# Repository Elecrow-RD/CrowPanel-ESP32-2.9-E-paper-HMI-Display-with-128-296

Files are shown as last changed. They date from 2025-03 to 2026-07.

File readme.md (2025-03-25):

### 1, Product picture

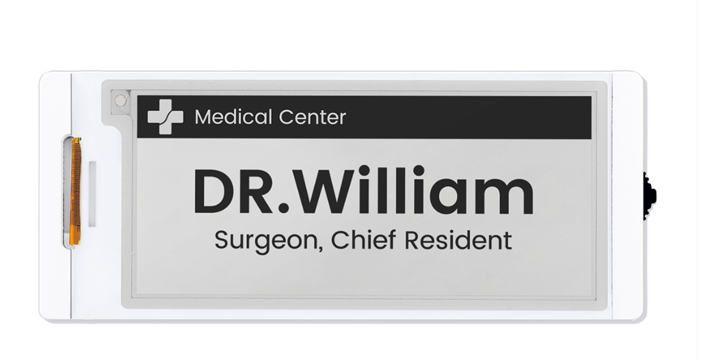
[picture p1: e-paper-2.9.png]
e-paper-2.9


### 2, Product version number

| | Hardware | Software | Remark |
| ---- | --- | --- | --- |
| 1 | V1.0 | V1.0 | latest |

### 3, product information

#### Display Module Specifications

- Size: 2.9 inch
- MCU: ESP32-S3-WROOM-1-N8R8, up to 240 MHz
- Flash: 8 MB
- PSRAM: 8 MB
- Material: Active Matrix Electrophoretic Display (AM EPD)
- Driver Chip: SSD1680Z
- Resolution: 128(H)*296(V) Pixel
- Pixel pitch: 0.227*0.226
- Viewing Angle: Full Viewing Angle
- Communication interface: 3-/4-wire SPI
- Interface: UART0 x1, BAT x1, GPIO x1, TF Card x1
- Button: Dial Switch x1, Menu Button x1, Back Button x1, REST Button x1, BOOT Button x1
- Development Environment: Arduino IDE、ESP IDF、MicroPython
- Display Color: Black and white
- Refresh Mode: Partial refresh (saves more power)
- Display Operation Voltage: 2.2~3.7V
- Acrylic Case: White Acrylic Case
- Operation Temperature: -0~50℃
- Storage Temperature: -25~70℃
- Active Area: 29.056(H)\*66.896(L) (H*L)

### 4, Use the driver module

| Name | dependency library |
| --- | --- |
| SSD1680Z | EPD<br />version=1.0.0 |

### 5,Quick Start

##### Arduino IDE starts

1.Download the library files used by this product to the 'libraries' folder.

C:\Users\Documents\Arduino\libraries\



2.Open the Arduino IDE

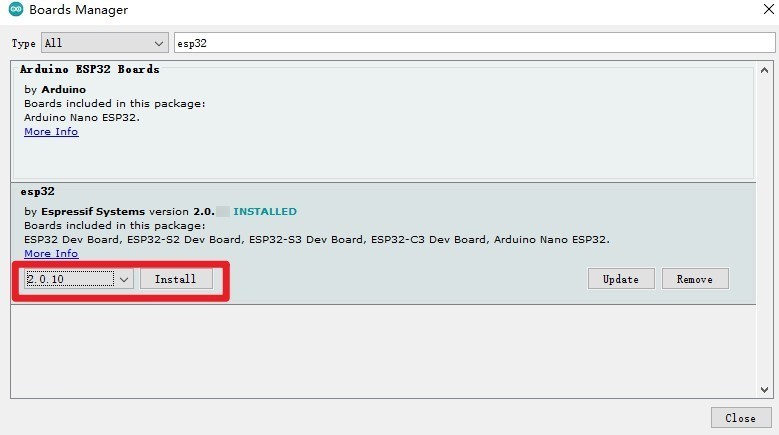
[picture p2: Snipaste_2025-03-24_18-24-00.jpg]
Snipaste_2025-03-24_18-24-00


3.Open the code configuration environment and burn it

setting

### 6,Folder structure.

|--3D file： Contains 3D model files (.stp) for the hardware. These files can be used for visualization, enclosure design, or integration into CAD software.

|--Datasheet: Includes datasheets for components used in the project, providing detailed specifications, electrical characteristics, and pin configurations.

|--Eagle_SCH&PCB: Contains **Eagle CAD** schematic (`.sch`) and PCB layout (`.brd`) files. These are used for circuit design and PCB manufacturing.

|--example: Provides example code and projects to demonstrate how to use the hardware and libraries. These examples help users get started quickly.

|--factory_firmware: Stores pre-compiled factory firmware that can be directly flashed onto the device. This ensures the device runs the default functionality.

|--factory_sourcecode: Contains the source code for the factory firmware, allowing users to modify and rebuild the firmware as needed.

### 7,Pin definition

#define SCK 12

#define MOSI 11

#define RES 47

#define DC 46

#define CS 45

#define BUSY 48

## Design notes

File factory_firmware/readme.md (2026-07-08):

# How to install the factory demo firmware with flash download tool?

#### 1.Preparation:

- USB C cable
- Laptop/PC
- Crowpanel Advance HMI ESP32 AI Display
- Flash download tool

Check whether the materials on the PCBA board are defective. Such as less material, false welding, tin and other bad phenomena.

#### 2.Flash the firmware 

##### Step1 Connect the ESP32 display to the laptop/PC with USB-C cable. The power indicator will light up.

##### Step2 Open the flash download tool. 

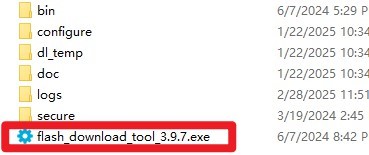
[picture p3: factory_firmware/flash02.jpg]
flash02


For the  Crowpanel Advance HMI ESP32 AI Display, the chip select ESP32-S3:

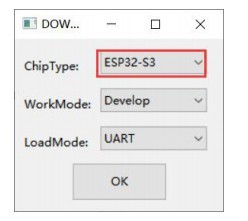
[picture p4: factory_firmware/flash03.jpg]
flash03


##### Step3

①Choose the firmware files;

flash0

②Enter the address: 

boot_app0.bin------0xe000

xxxx.ino.bin--------0x10000

xxxx.ino.bootloader.bin------0x0

xxxx.ino.partitions.bin-------0x8000

③Check the firmware files;

④Select the correct port number;

⑤Click “Start” to download

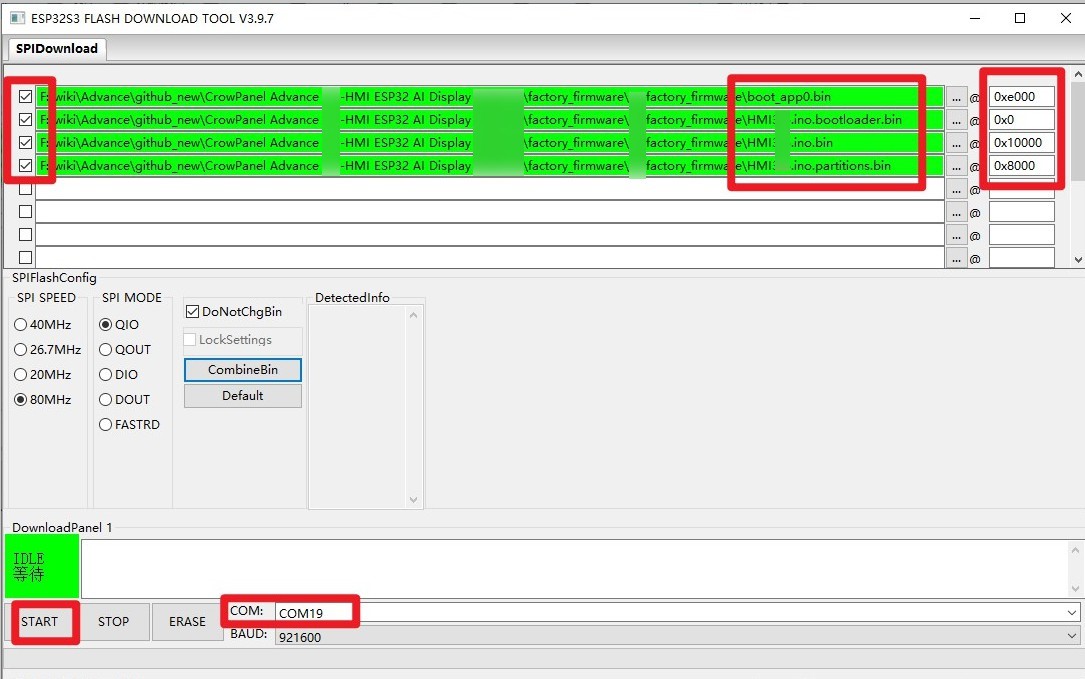
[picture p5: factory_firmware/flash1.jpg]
flash1


##### Step5 After the download is complete, blue FINISH will be displayed, and the progress bar at the bottom shows that it has come to an end.

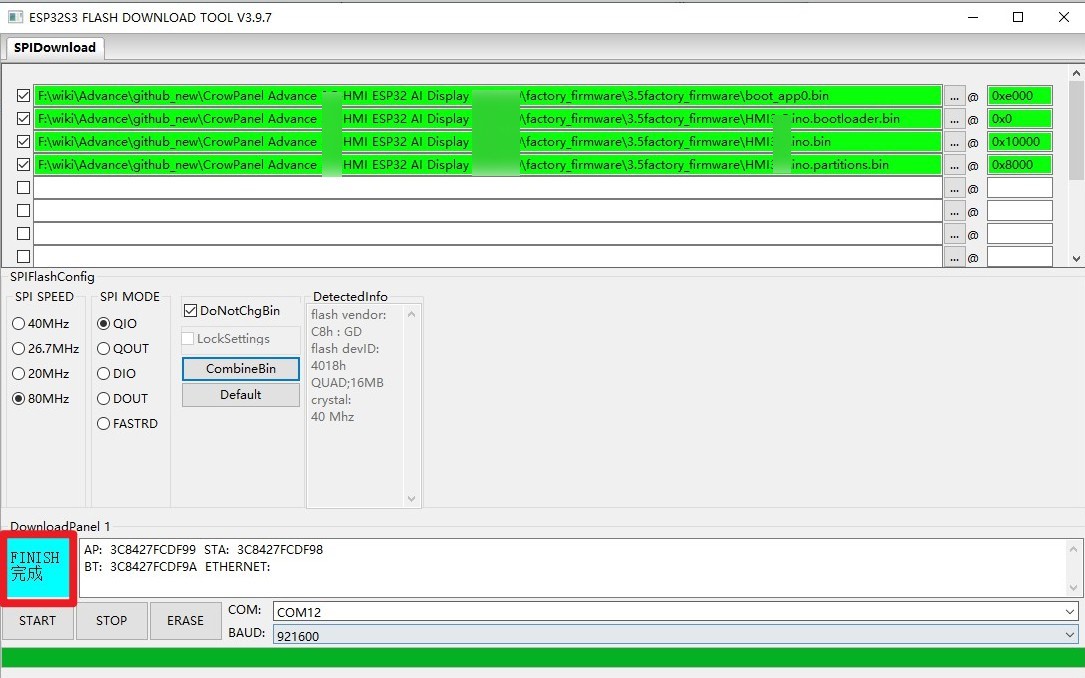
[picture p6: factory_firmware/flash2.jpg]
flash2


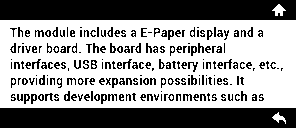
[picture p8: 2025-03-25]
factory_sourecode/2.9_tow/pic/NEW_UI_2-9_BW_/NEW_UI_2-9_BW_Product-Description-03.bmp

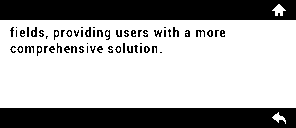
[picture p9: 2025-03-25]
factory_sourecode/2.9_tow/pic/NEW_UI_2-9_BW_/NEW_UI_2-9_BW_Product-Description-06.bmp

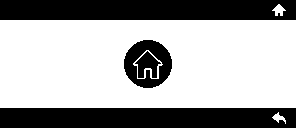
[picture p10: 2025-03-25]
factory_sourecode/2.9_tow/pic/ui_2-9_202406_02/UI_2_9_202406返回主界面.bmp

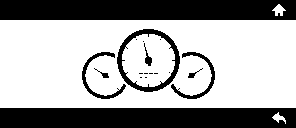
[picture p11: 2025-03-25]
factory_sourecode/2.9_tow/pic/NEW_UI_2-9_BW_/NEW_UI_2-9_BW_img-03.bmp

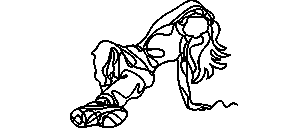
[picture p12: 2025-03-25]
factory_sourecode/2.9_tow/pic/NEW_UI_2-9_BW_/NEW_UI_2-9_BW_img-06.bmp

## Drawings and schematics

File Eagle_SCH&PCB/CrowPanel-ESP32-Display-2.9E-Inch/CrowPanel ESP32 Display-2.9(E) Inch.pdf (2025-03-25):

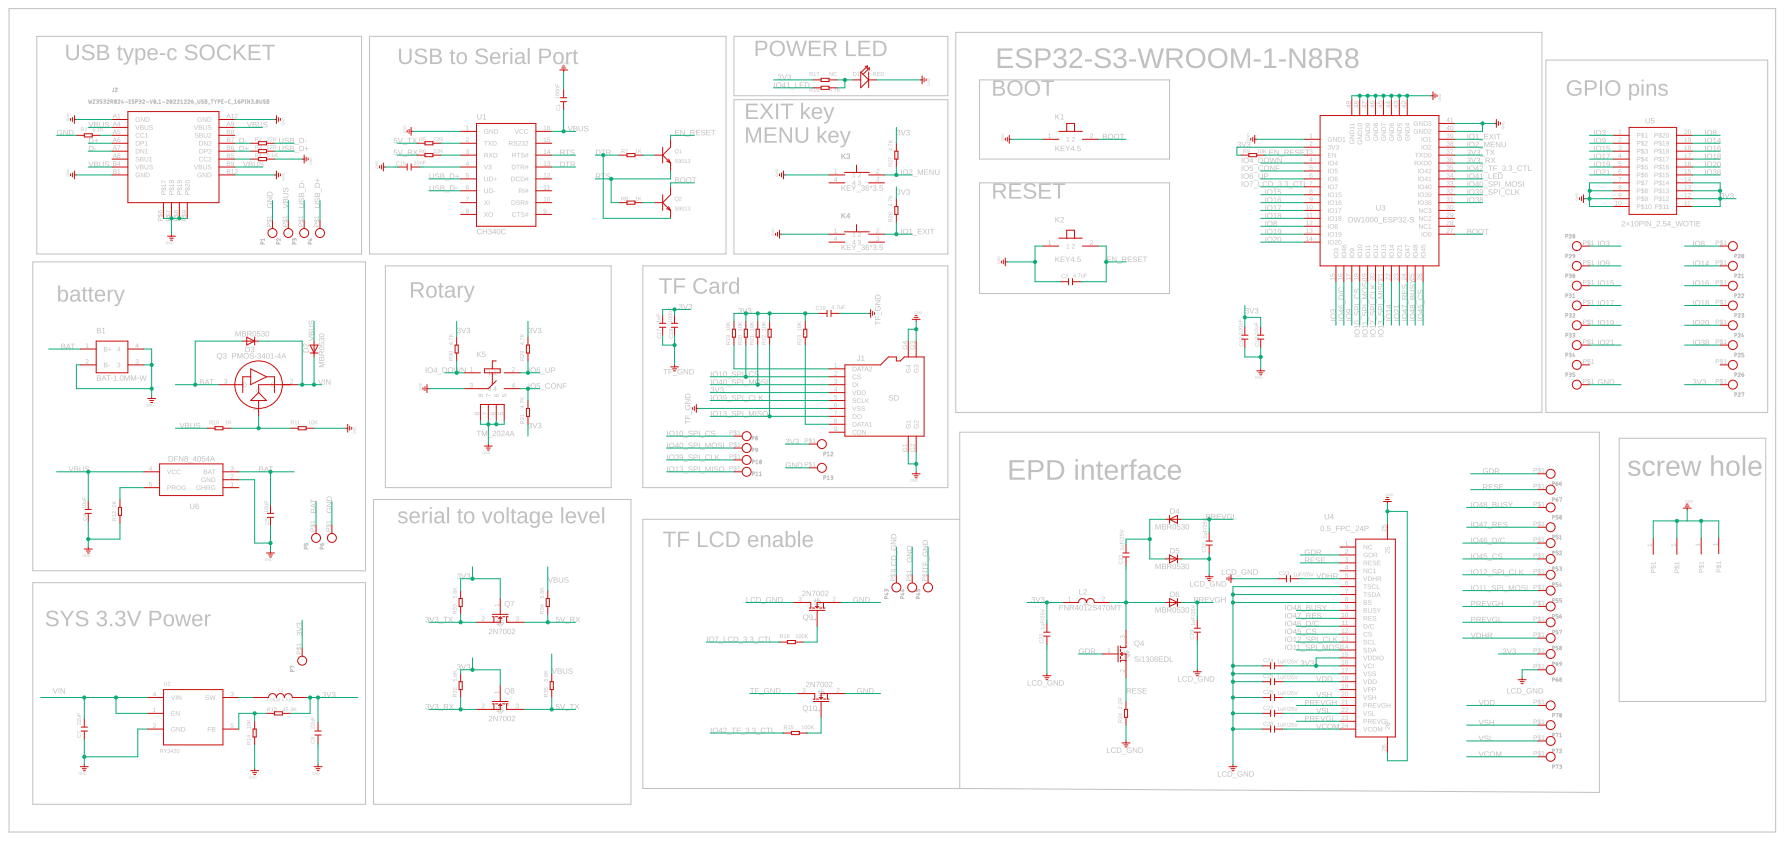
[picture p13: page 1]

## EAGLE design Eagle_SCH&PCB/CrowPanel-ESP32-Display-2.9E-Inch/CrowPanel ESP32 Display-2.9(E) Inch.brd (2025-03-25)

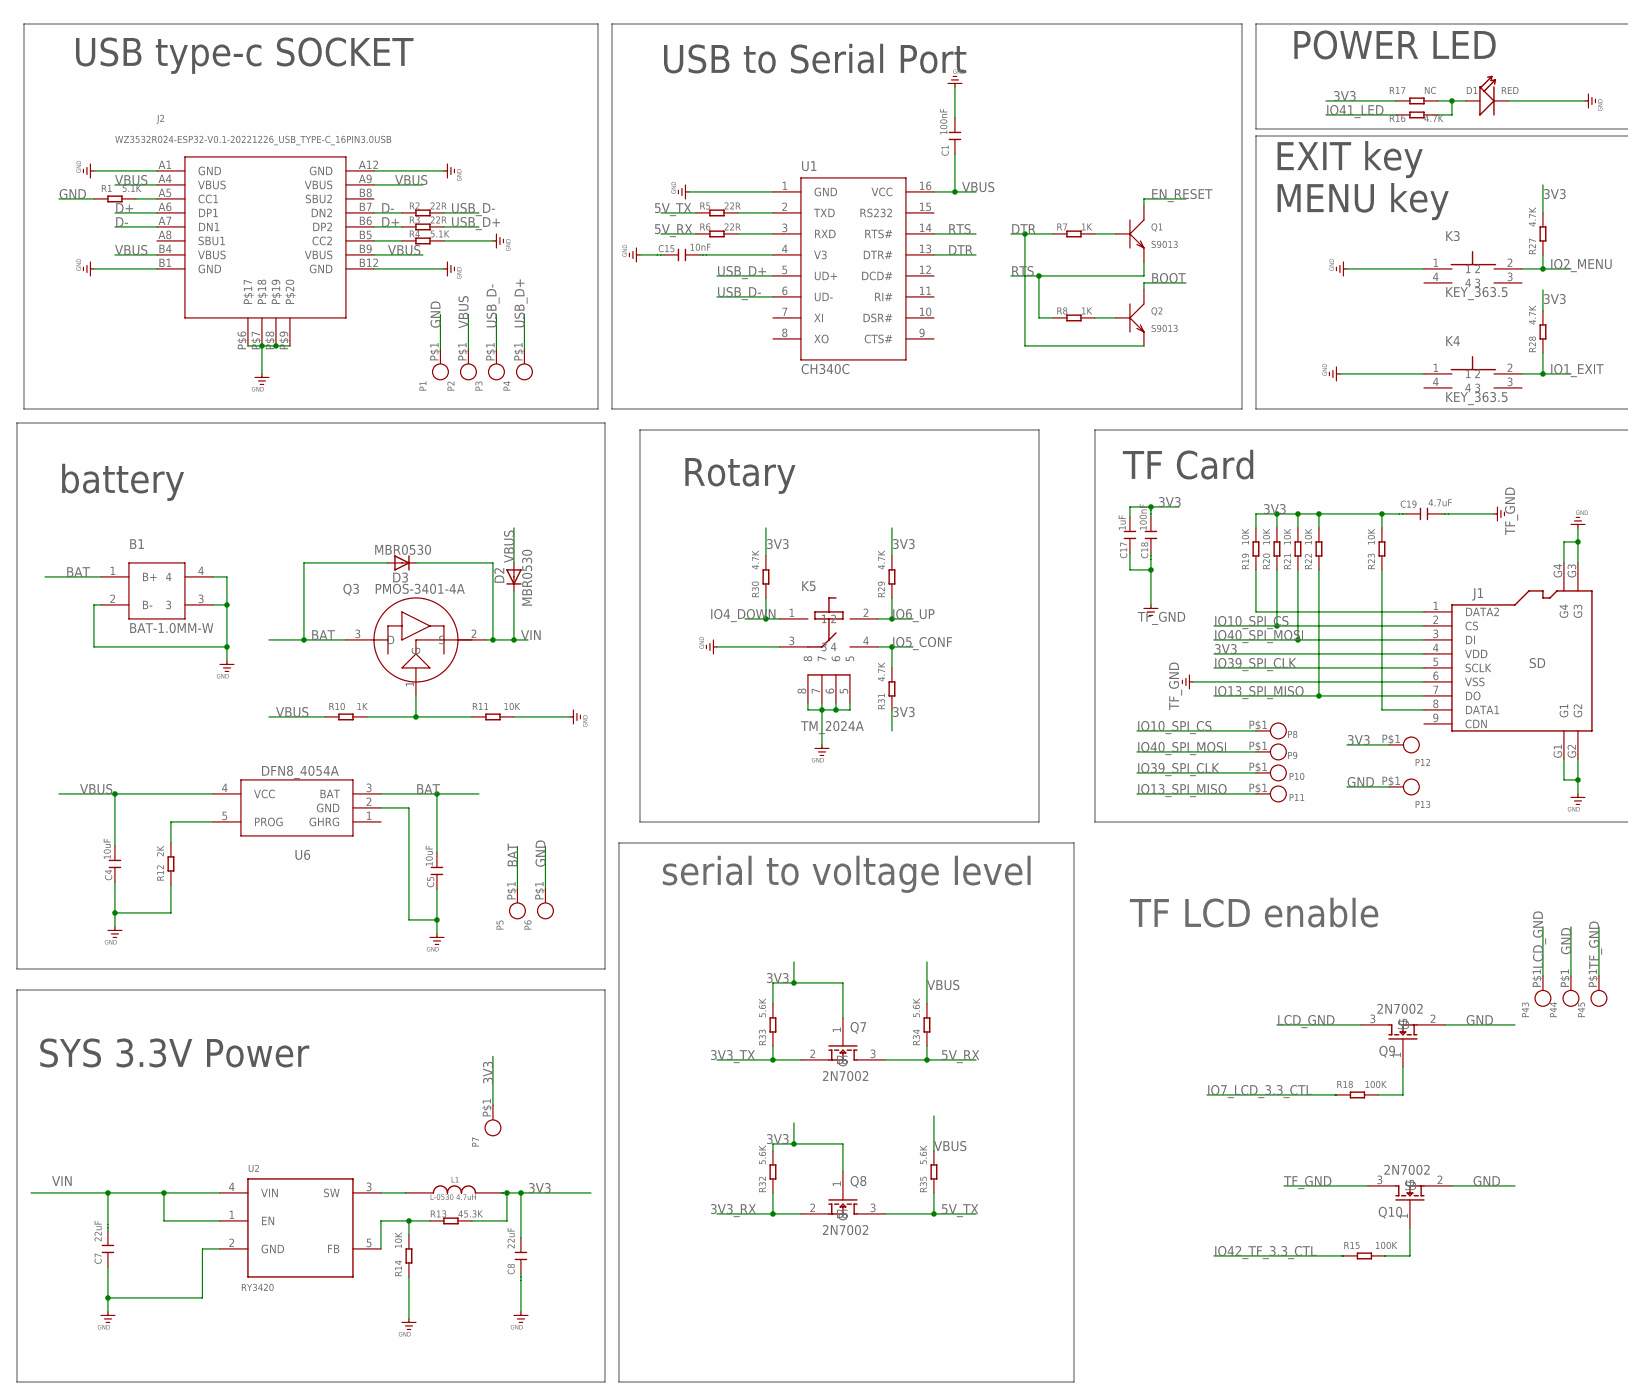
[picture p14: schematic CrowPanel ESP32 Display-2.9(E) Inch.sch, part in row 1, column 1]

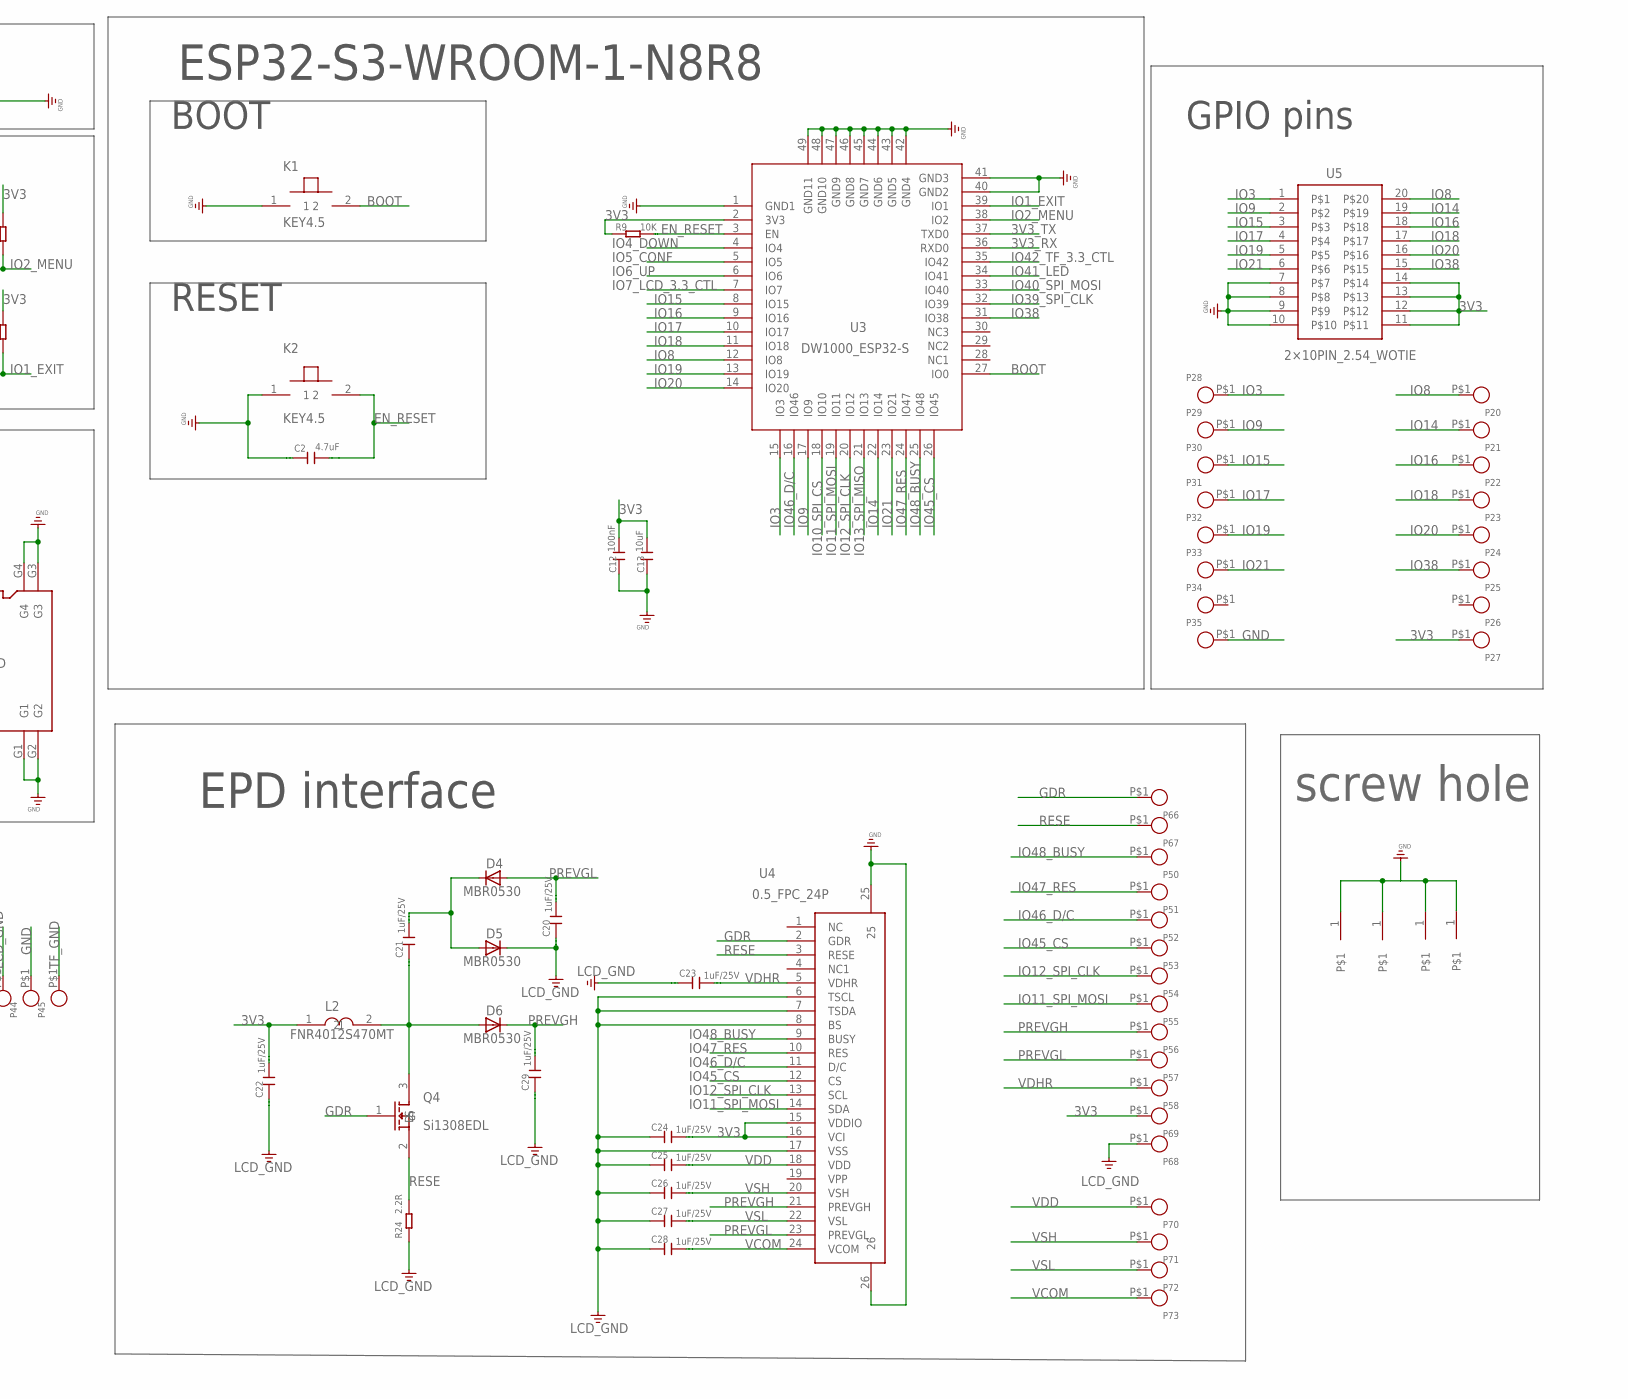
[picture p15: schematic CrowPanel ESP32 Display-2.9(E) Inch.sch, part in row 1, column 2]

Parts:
B1: BAT-1.0MM-W; SH1.0MM-W
C1, C12, C18: 100nF; 0402
C2, C19: 4.7uF; 0402
C4, C5, C13: 10uF; 0402
C7, C8: 22uF; 0603
C15: 10nF; 0402
C17: 1uF; 0402
C20, C21, C22, C23, C24, C25, C26, C27, C28, C29: 1uF/25V; 0402
D1: RED; A_XBJ_DISCRETE_LED-0603
D2, D3, D4, D5, D6: MBR0530; DIODE_SOD123
H1, H2, H3, H4: DW1000_3.2MM-5
J1: SD; CONNECTOR_9P-SMD-W/-RING
J2: WZ3532R024-ESP32-V0.1-20221226_USB_TYPE-C_16PIN3.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; WZ3532R024-ESP32-V0.1-20221226_KEVIN_3.0TYPEC-SMD
K1, K2: KEY4.5; KEY-4.5
K3, K4: KEY_363.5; KEY_3*6*3.5
K5: TM_2024A
L1: L-0530 4.7uH; L0530
L2: FNR4012S470MT
P1, P2, P3, P4, P5, P6, P7, P8, P9, P10, P11, P12, P13, P20, P21, P22, P23, P24, P25, P26, P27, P28, P29, P30, P31, P32, P33, P34, P35, P43, P44, P45, P50, P51, P52, P53, P54, P55, P56, P57, P58, P66, P67, P68, P69, P70, P71, P72, P73: CROWPI_POW_PADPAD-1.0MM; CROWPI_POW_PAD-1.0MM
Q1, Q2: S9013; DISCRETE_SOT23$1
Q3: PMOS-3401-4A; DFN8_SOT-23
Q4: Si1308EDL; SOT-323_W
Q7, Q8, Q9, Q10: 2N7002; SOT23-3_W
R1, R4: 5.1K; 0402
R2, R3, R5, R6: 22R; 0402
R7, R8, R10: 1K; 0402
R9, R11, R14, R19, R20, R21, R22, R23: 10K; 0402
R12: 2K; 0402
R13: 45.3K; 0402
R15, R18: 100K; 0402
R16, R27, R28, R29, R30, R31: 4.7K; A9G_DISCRETE_R0603
R17: NC; A9G_DISCRETE_R0603
R24: 2.2R; 0402
R32, R33, R34, R35: 5.6K; 0402
U1: CH340C; A_XBJ_SOP-16
U2: RY3420; CROWBOT_-V1.0-20220525_A_XBJ_SOT23-5
U3: DW1000_ESP32-S; DW1000_ESP32-S3
U4: 0.5_FPC_24P
U5: 2×10PIN_2.54_WOTIE; 2*10PIN_2.54_WOTIE
U6: DFN8_4054A; DFN8_SOP23-5

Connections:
3V3: C8.2, C12.2, C13.2, C17.2, C18.2, C19.1, C22.1, C24.1, J1.4 (VDD), L1.P$2 (2), L2.1, P7.P$1, P12.P$1, P27.P$1, P69.P$1, Q7.1 (G), Q8.1 (G), R9.1, R13.2, R17.1, R19.2, R20.2, R21.2, R22.2, R23.2, R27.2, R28.2, R29.2, R30.2, R31.1, R32.2, R33.2, U3.2 (3V3), U4.15 (VDDIO), U4.16 (VCI), U5.11, U5.12, U5.13, U5.14
3V3_RX: Q8.2 (S), R32.1, U3.36 (RXD0)
3V3_TX: Q7.2 (S), R33.1, U3.37 (TXD0)
5V_RX: Q7.3 (D), R6.1, R34.1
5V_TX: Q8.3 (D), R5.1, R35.1
BAT: B1.1 (B+), C5.2, D3.A, P5.P$1, Q3.3 (D), U6.3 (BAT)
BOOT: K1.2, Q2.3 (C), U3.27 (IO0)
D+: J2.A6 (DP1), J2.B6 (DP2), R3.1
D-: J2.A7 (DN1), J2.B7 (DN2), R2.1
DTR: Q2.2 (E), R7.1, U1.13 (DTR#)
EN_RESET: C2.2, K2.2, Q1.3 (C), R9.2, U3.3 (EN)
GDR: P66.P$1, Q4.1 (G), U4.2 (GDR)
GND: B1.2 (B-), B1.3, B1.4, C1.2, C2.1, C4.1, C5.1, C7.1, C8.1, C12.1, C13.1, C15.1, D1.-, H1.1, H2.1, H3.1, H4.1, J1.G1, J1.G2, J1.G3, J1.G4, J2.A1 (GND), J2.A12 (GND), J2.B1 (GND), J2.B12 (GND), J2.P$6, J2.P$7, J2.P$8, J2.P$9, K1.1, K2.1, K3.1, K4.1, K5.3, K5.5, K5.6, K5.7, K5.8, P1.P$1, P6.P$1, P13.P$1, P35.P$1, P44.P$1, Q9.2 (S), Q10.2 (S), R1.1, R4.2, R11.2, R12.1, R14.1, U1.1 (GND), U2.2 (GND), U3.1 (GND1), U3.40 (GND2), U3.41 (GND3), U3.42 (GND4), U3.43 (GND5), U3.44 (GND6), U3.45 (GND7), U3.46 (GND8), U3.47 (GND9), U3.48 (GND10), U3.49 (GND11), U4.25, U4.26, U5.7, U5.8, U5.9, U5.10, U6.2 (GND)
IO1_EXIT: K4.2, R28.1, U3.39 (IO1)
IO2_MENU: K3.2, R27.1, U3.38 (IO2)
IO3: P28.P$1, U3.15 (IO3), U5.1
IO4_DOWN: K5.1, R30.1, U3.4 (IO4)
IO5_CONF: K5.4, R31.2, U3.5 (IO5)
IO6_UP: K5.2, R29.1, U3.6 (IO6)
IO7_LCD_3.3_CTL: R18.1, U3.7 (IO7)
IO8: P20.P$1, U3.12 (IO8), U5.20
IO9: P29.P$1, U3.17 (IO9), U5.2
IO10_SPI_CS: J1.2 (CS), P8.P$1, R20.1, U3.18 (IO10)
IO11_SPI_MOSI: P55.P$1, U3.19 (IO11), U4.14 (SDA)
IO12_SPI_CLK: P54.P$1, U3.20 (IO12), U4.13 (SCL)
IO13_SPI_MISO: J1.7 (DO), P11.P$1, R22.1, U3.21 (IO13)
IO14: P21.P$1, U3.22 (IO14), U5.19
IO15: P30.P$1, U3.8 (IO15), U5.3
IO16: P22.P$1, U3.9 (IO16), U5.18
IO17: P31.P$1, U3.10 (IO17), U5.4
IO18: P23.P$1, U3.11 (IO18), U5.17
IO19: P32.P$1, U3.13 (IO19), U5.5
IO20: P24.P$1, U3.14 (IO20), U5.16
IO21: P33.P$1, U3.23 (IO21), U5.6
IO38: P25.P$1, U3.31 (IO38), U5.15
IO39_SPI_CLK: J1.5 (SCLK), P10.P$1, U3.32 (IO39)
IO40_SPI_MOSI: J1.3 (DI), P9.P$1, R21.1, U3.33 (IO40)
IO41_LED: R16.1, U3.34 (IO41)
IO42_TF_3.3_CTL: R15.1, U3.35 (IO42)
IO45_CS: P53.P$1, U3.26 (IO45), U4.12 (CS)
IO46_D/C: P52.P$1, U3.16 (IO46), U4.11 (D/C)
IO47_RES: P51.P$1, U3.24 (IO47), U4.10 (RES)
IO48_BUSY: P50.P$1, U3.25 (IO48), U4.9 (BUSY)
LCD_GND: C20.2, C22.2, C23.2, C24.2, C25.2, C26.2, C27.2, C28.2, C29.2, D5.C, P43.P$1, P68.P$1, Q9.3 (D), R24.1, U4.6 (TSCL), U4.7 (TSDA), U4.8 (BS), U4.17 (VSS)
unnamed: Q1.1 (B), R7.2
unnamed: R5.2, U1.2 (TXD)
unnamed: R6.2, U1.3 (RXD)
unnamed: Q2.1 (B), R8.2
unnamed: J2.A5 (CC1), R1.2
unnamed: Q3.1 (G), R10.2, R11.1
unnamed: Q9.1 (G), R18.2
unnamed: Q10.1 (G), R15.2
unnamed: R13.1, R14.2, U2.5 (FB)
unnamed: J1.1 (DATA2), R19.1
unnamed: L1.P$1 (1), U2.3 (SW)
unnamed: J2.B5 (CC2), R4.1
unnamed: C15.2, U1.4 (V3)
unnamed: R12.2, U6.5 (PROG)
unnamed: J1.8 (DATA1), R23.1
unnamed: D1.+, R16.2, R17.2
unnamed: C21.1, D4.C, D5.A
unnamed: C21.2, D6.A, L2.2, Q4.3 (D)
PREVGH: C29.1, D6.C, P56.P$1, U4.21 (PREVGH)
PREVGL: C20.1, D4.A, P57.P$1, U4.23 (PREVGL)
RESE: P67.P$1, Q4.2 (S), R24.2, U4.3 (RESE)
RTS: Q1.2 (E), R8.1, U1.14 (RTS#)
TF_GND: C17.1, C18.1, C19.2, J1.6 (VSS), P45.P$1, Q10.3 (D)
USB_D+: P4.P$1, R3.2, U1.5 (UD+)
USB_D-: P3.P$1, R2.2, U1.6 (UD-)
VBUS: C1.1, C4.2, D2.A, J2.A4 (VBUS), J2.A9 (VBUS), J2.B4 (VBUS), J2.B9 (VBUS), P2.P$1, R10.1, R34.2, R35.2, U1.16 (VCC), U6.4 (VCC)
VCOM: C28.1, P73.P$1, U4.24 (VCOM)
VDD: C25.1, P70.P$1, U4.18 (VDD)
VDHR: C23.1, P58.P$1, U4.5 (VDHR)
VIN: C7.2, D2.C, D3.C, Q3.2 (S), U2.1 (EN), U2.4 (VIN)
VSH: C26.1, P71.P$1, U4.20 (VSH)
VSL: C27.1, P72.P$1, U4.22 (VSL)

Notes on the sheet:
USB type-c SOCKET
USB to Serial Port
POWER LED
EXIT key MENU key
ESP32-S3-WROOM-1-N8R8
GPIO pins
EPD interface
TF Card
Rotary
SYS 3.3V Power
battery
BOOT
RESET
serial to voltage level
TF LCD enable
screw hole

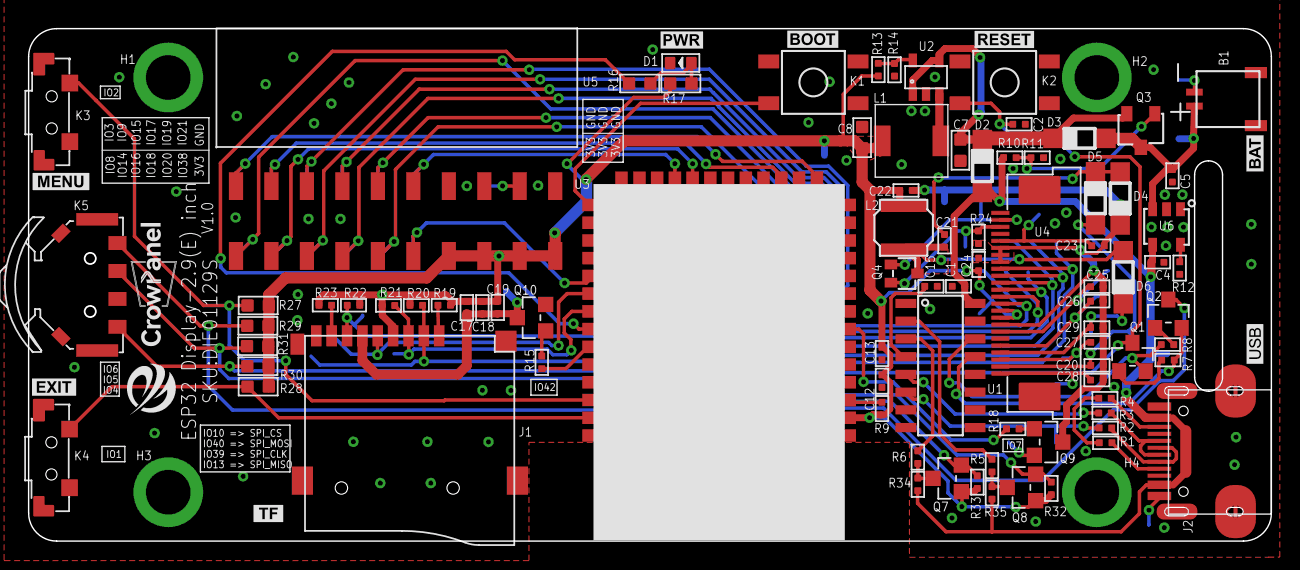
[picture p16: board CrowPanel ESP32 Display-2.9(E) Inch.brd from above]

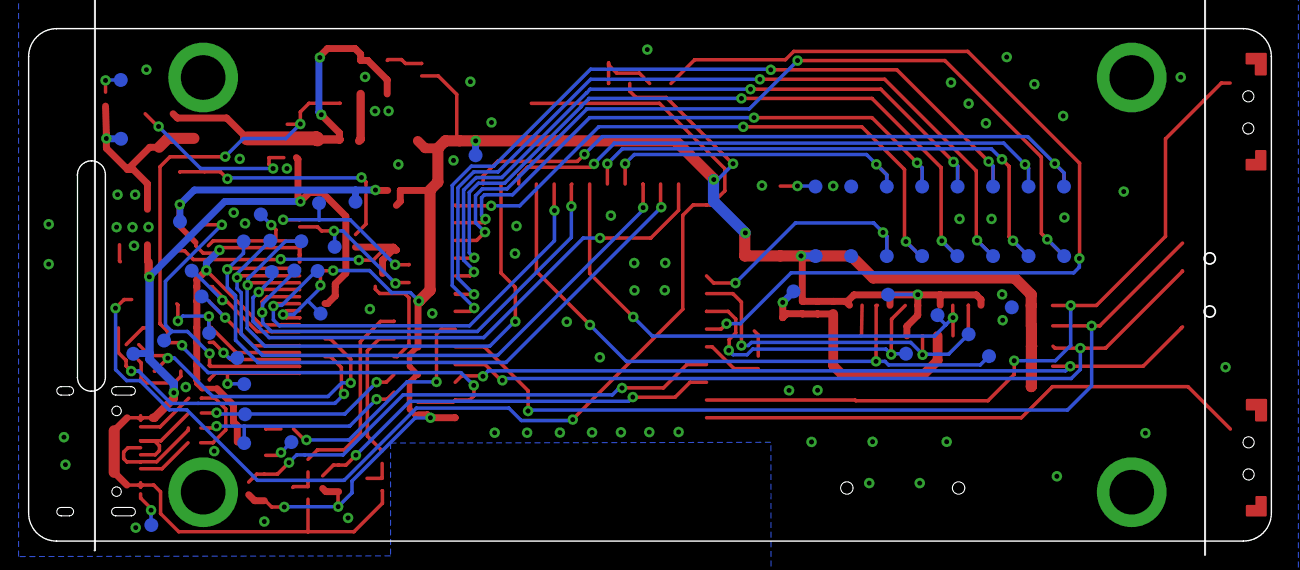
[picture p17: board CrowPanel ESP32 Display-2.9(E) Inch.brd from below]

Board: 2 copper layers, 89.0 x 36.7 mm, 140 parts (49 on the bottom side), 76 nets.

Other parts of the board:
U$30: LOGO-1
U$41: LOGO-MIN

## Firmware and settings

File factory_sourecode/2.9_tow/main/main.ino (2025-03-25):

#include <Arduino.h>
#include "EPD.h"
#include "pic.h"
#include "Pic_boot_screen.h"
#include "pic_menu.h"
#include "pic_home.h"
#include "pic_description.h"
#include "pic_image.h"
#include "pic_scenario.h"

#include "FS.h"
#include "SD.h"
#include <WiFi.h>
//#include <esp_wifi.h>

#define FILE_NAME "/book.txt"
#define SD_MOSI 40
#define SD_MISO 13
#define SD_SCK 39
#define SD_CS 10
SPIClass SD_SPI = SPIClass(HSPI);

#include "BLEDevice.h"              //BLE驱动库
#include "BLEServer.h"              //BLE蓝牙服务器库
#include "BLEUtils.h"               //BLE实用程序库
#include "BLE2902.h"                //特征添加描述符库
BLECharacteristic *pCharacteristic;
BLEServer *pServer;
BLEService *pService;
bool deviceConnected = false;
char BLEbuf[32] = {0};
uint32_t cnt = 0;

#define SERVICE_UUID           "6E400001-B5A3-F393-E0A9-E50E24DCCA9E" // UART service UUID
#define CHARACTERISTIC_UUID_RX "6E400002-B5A3-F393-E0A9-E50E24DCCA9E"
#define CHARACTERISTIC_UUID_TX "6E400003-B5A3-F393-E0A9-E50E24DCCA9E"

class MyServerCallbacks: public BLEServerCallbacks {
    void onConnect(BLEServer* pServer) {
      deviceConnected = true;
      Serial.println("------> BLE connect .");
    };

    void onDisconnect(BLEServer* pServer) {
      deviceConnected = false;
      Serial.println("------> BLE disconnect .");
      pServer->startAdvertising(); // restart advertising
      Serial.println("start advertising");
    }
};

class MyCallbacks: public BLECharacteristicCallbacks {
    void onWrite(BLECharacteristic *pCharacteristic) {
      std::string rxValue = pCharacteristic->getValue();

      if (rxValue.length() > 0) {
        Serial.print("------>Received Value: ");

        for (int i = 0; i < rxValue.length(); i++) {
          Serial.print(rxValue[i]);
        }
        Serial.println();

        if (rxValue.find("A") != -1) {
          Serial.print("Rx A!");
        }
        else if (rxValue.find("B") != -1) {
          Serial.print("Rx B!");
        }
        Serial.println();
      }
    }
};

//打印唤醒原因
void print_wakeup_reason() {
  esp_sleep_wakeup_cause_t wakeup_reason;

  wakeup_reason = esp_sleep_get_wakeup_cause();

  switch (wakeup_reason)
  {
    case ESP_SLEEP_WAKEUP_EXT0 : Serial.println("Wakeup caused by external signal using RTC_IO"); break;
    case ESP_SLEEP_WAKEUP_EXT1 : Serial.println("Wakeup caused by external signal using RTC_CNTL"); break;
    case ESP_SLEEP_WAKEUP_TIMER : Serial.println("Wakeup caused by timer"); break;
    case ESP_SLEEP_WAKEUP_TOUCHPAD : Serial.println("Wakeup caused by touchpad"); break;
    case ESP_SLEEP_WAKEUP_ULP : Serial.println("Wakeup caused by ULP program"); break;
    default : Serial.printf("Wakeup was not caused by deep sleep: %d\n", wakeup_reason); break;
  }
}

//主页键
#define HOME_KEY 2
//退出键
#define EXIT_KEY 1

//轮播开关
//上一页
#define PRV_KEY 6
//下一页
#define NEXT_KEY 4
//确认
#define OK_KEY 5

int peg_pos;  //页游标
int slide_pos; //界面游标
int8_t prv_menu_pos;
int three_interface_flag; //三级界面标志
int scenario_ctl;  //开关标志
int scenario_ctl1;
int scenario_ctl2;
int scenario_ctl3;
int scenario_ctl4;
int sleep_num; //进去睡眠计数
bool test_flag;
char val;
int KEY_NUM;
extern uint8_t ImageBW[ALLSCREEN_BYTES];


void clear_all()
{
  EPD_Init();
  EPD_Clear(0, 0, 296, 128, WHITE);
  EPD_ALL_Fill(WHITE);
  EPD_Update();
  EPD_Clear_R26H();
}

void setup()
{
  sleep_num = 0;
  Serial.begin(115200);
  //POWER灯
  pinMode(41, OUTPUT);
  digitalWrite(41, HIGH);
  //屏电源
  pinMode(7, OUTPUT);
  digitalWrite(7, HIGH);
  //SD卡电源
  pinMode(42, OUTPUT);
  digitalWrite(42, HIGH);

  pinMode(HOME_KEY, INPUT);
  pinMode(EXIT_KEY, INPUT);
  pinMode(PRV_KEY, INPUT);
  pinMode(NEXT_KEY, INPUT);
  pinMode(OK_KEY, INPUT);
  //GPIO输出模式
  pinMode(8, OUTPUT);
  pinMode(3, OUTPUT);
  pinMode(14, OUTPUT);
  pinMode(9, OUTPUT);
  pinMode(16, OUTPUT);
  pinMode(15, OUTPUT);
  pinMode(18, OUTPUT);
  pinMode(17, OUTPUT);
  pinMode(20, OUTPUT);
  pinMode(19, OUTPUT);
  pinMode(38, OUTPUT);
  pinMode(21, OUTPUT);
  //  pinMode(40, OUTPUT);
  //  pinMode(39, OUTPUT);

  //Print the wakeup reason for ESP32
  print_wakeup_reason();
  //First we configure the wake up source
  esp_sleep_enable_ext0_wakeup(GPIO_NUM_2, 0); //1 = High, 0 = Low

  // Create the BLE Device
  BLEDevice::init("CrowPanel2-9");
  // 创建蓝牙服务器
  pServer = BLEDevice::createServer();
  pServer->setCallbacks(new MyServerCallbacks());
  // 创建广播服务的UUID
  pService = pServer->createService(SERVICE_UUID);
  //  //创建广播服务的UUID
  pCharacteristic = pService->createCharacteristic(CHARACTERISTIC_UUID_TX, BLECharacteristic::PROPERTY_NOTIFY);
  pCharacteristic->addDescriptor(new BLE2902());
  BLECharacteristic *pCharacteristic = pService->createCharacteristic(CHARACTERISTIC_UUID_RX, BLECharacteristic::PROPERTY_WRITE);
  pCharacteristic->setCallbacks(new MyCallbacks());
  //  pServer->getAdvertising()->start();

  EPD_Init();
  EPD_Clear(0, 0, 296, 128, WHITE);
  EPD_ALL_Fill(WHITE);
  EPD_Update();
  EPD_Clear_R26H();

  EPD_ShowPicture(0, 0, 296, 128, gImage_boot_setup, BLACK);
  EPD_DisplayImage(ImageBW);
  EPD_FastUpdate();
  //  EPD_PartUpdate();
  EPD_Sleep();
  delay(500);

  EPD_HW_RESET();
  EPD_ShowPicture(0, 0, 296, 128, gImage_boot_setup_1, BLACK);
  EPD_DisplayImage(ImageBW);
  EPD_FastUpdate();
  //  EPD_PartUpdate();
  EPD_Sleep();
  delay(500);

  EPD_HW_RESET();
  EPD_ShowPicture(0, 0, 296, 128, gImage_boot_setup_info, BLACK);
  EPD_DisplayImage(ImageBW);
  EPD_FastUpdate();
  //  EPD_PartUpdate();
  EPD_Sleep();
  delay(500);

  clear_all();
  EPD_HW_RESET();
  EPD_ShowPicture(0, 0, 296, 128, gImage_menu, BLACK);
  EPD_DisplayImage(ImageBW);
  //  EPD_FastUpdate();
  EPD_PartUpdate();
  EPD_Sleep();

  peg_pos = 1;
  slide_pos = 0;
  prv_menu_pos = 0;
  three_interface_flag = 0;
  test_flag = false;
  scenario_ctl = 0;
  scenario_ctl1 = 0;
  scenario_ctl2 = 0;
  scenario_ctl3 = 0;
  scenario_ctl4 = 0;

}

int KEY_SCAN()
{

  if (test_flag != false)
  {
    //    Serial.println(" ....... ");
    return 0;
  }

  KEY_NUM = 0;
  if (digitalRead(HOME_KEY) == 0)
  {
    delay(80);
    int i = 0;
    if (digitalRead(HOME_KEY) == 0)
    {
      Serial.println("HOME_KEY");
      sleep_num = 0;
      Serial.println("sleep now clear");
      while (digitalRead(HOME_KEY) == 0)  //长按5s清屏
      {
        i++;
        Serial.print("HOME_KEY KEEP ");
        Serial.println(i);
        delay(10);
        if (i == 500)
        {
          Serial.println("Display_Clear ....... ");
          clear_all();
          EPD_Sleep();
          while (1);
          return 0;
        }
      }
      KEY_NUM = 1;
    }
  }
  else if (digitalRead(EXIT_KEY) == 0)
  {
    delay(80);
    if (digitalRead(EXIT_KEY) == 0)
    {
      Serial.println("EXIT_KEY");
      KEY_NUM = 2;
    }
  }
  else if (digitalRead(PRV_KEY) == 0)
  {
    delay(80);
    if (digitalRead(PRV_KEY) == 0)
    {
      Serial.println("PRV_KEY");
      KEY_NUM = 3;
    }
  }
  else if (digitalRead(NEXT_KEY) == 0)
  {
    delay(80);
    if (digitalRead(NEXT_KEY) == 0)
    {
      Serial.println("NEXT_KEY");
      KEY_NUM = 4;
    }
  }
  else if (digitalRead(OK_KEY) == 0)
  {
    delay(80);
    if (digitalRead(OK_KEY) == 0)
    {
      Serial.println("OK_KEY");
      KEY_NUM = 5;
    }
  }

  return KEY_NUM;
}

void test_title()
{
  EPD_GPIOInit();
  clear_all();
  EPD_ShowString(75, 48, "Test Program", BLACK, 24);
  EPD_DisplayImage(ImageBW);
  EPD_FastUpdate();
  //    EPD_PartUpdate();
  EPD_Sleep();

}
void key_test()
{
  char command[64] = {0};   //串口收到的命令
  char count = 0;           //命令的长度
  while (1)
  {
    while (Serial.available())
    {
      val = Serial.read();
      Serial.print("read key com data: ");
      Serial.print(val);
      Serial.println("");
      command[count] = val;
      count++;
    }
    if (command[0] == 'c')
    {
      Serial.println("EXIT key test");
      break;
    }

    if (digitalRead(HOME_KEY) == 0)
    {
      delay(100);
      if (digitalRead(HOME_KEY) == 0)
      {
        Serial.println("HOME_KEY");
      }
    }
    else if (digitalRead(EXIT_KEY) == 0)
    {
      delay(100);
      if (digitalRead(EXIT_KEY) == 0)
      {
        Serial.println("EXIT_KEY");
      }
    }
    else if (digitalRead(PRV_KEY) == 0)
    {
      delay(100);
      if (digitalRead(PRV_KEY) == 0)
      {
        Serial.println("PRV_KEY");
      }
    }
    else if (digitalRead(NEXT_KEY) == 0)
    {
      delay(100);
      if (digitalRead(NEXT_KEY) == 0)
      {
        Serial.println("NEXT_KEY");
      }
    }
    else if (digitalRead(OK_KEY) == 0)
    {
      delay(100);
      if (digitalRead(OK_KEY) == 0)
      {
        Serial.println("OK_KEY");
      }
    }
  }
}

void wifi_test()
{
  char command[64] = {0};   //串口收到的命令
  char count = 0;           //命令的长度
  bool flag = false;
  bool timeout_flag = false;
  while (1)
  {
    while (Serial.available())
    {
      String ssid = Serial.readStringUntil(','); // 读取 SSID
      String password = Serial.readStringUntil('\n'); // 读取密码
      // 在这里处理 SSID 和密码
      Serial.print("SSID: ");
      Serial.println(ssid);
      Serial.print("Password: ");
      Serial.println(password);
      WiFi.begin(ssid, password);
      int timeout = 0;
      while (WiFi.status() != WL_CONNECTED) {
        delay(500);
        Serial.print(".");
        timeout++;
        if (timeout == 40)
        {
          Serial.println("Connection timeout exit");
          Serial.println("EXIT WIFI test");
          char command[64] = {0};   //串口收到的命令
          char count = 0;           //命令的长度
          return;
        }
      }
      if (timeout_flag == false)
      {
        Serial.println("");
        Serial.println("WiFi connected");
        Serial.println("IP address: ");
        Serial.println(WiFi.localIP());
        char command[64] = {0};   //串口收到的命令
        char count = 0;           //命令的长度
        flag = true;
      }
    }
    if (flag == true)
    {
      Serial.println("EXIT WIFI test");
      char command[64] = {0};   //串口收到的命令
      char count = 0;           //命令的长度
      break;
    }
    delay(10);
  }
}

void ble_test()
{
  char command[64] = {0};   //串口收到的命令
  char count = 0;           //命令的长度
  // Create the BLE Device
  //  BLEDevice::init("CrowPanel-ESP32S3");
  //  // 创建蓝牙服务器
  //  BLEServer *pServer = BLEDevice::createServer();
  //  pServer->setCallbacks(new MyServerCallbacks());
  //  // 创建广播服务的UUID
  //  BLEService *pService = pServer->createService(SERVICE_UUID);
  //  //创建广播服务的UUID
  //  pCharacteristic = pService->createCharacteristic(CHARACTERISTIC_UUID_TX, BLECharacteristic::PROPERTY_NOTIFY);
  //  pCharacteristic->addDescriptor(new BLE2902());
  //  BLECharacteristic *pCharacteristic = pService->createCharacteristic(CHARACTERISTIC_UUID_RX, BLECharacteristic::PROPERTY_WRITE);
  //  pCharacteristic->setCallbacks(new MyCallbacks());

  // 开始蓝牙服务
  pService->start();
  // 开始广播
  pServer->getAdvertising()->start();
  Serial.println("Waiting a client connection to notify...");

  while (1)
  {
    while (Serial.available())
    {
      val = Serial.read();
      Serial.print("read ble com data: ");
      Serial.print(val);
      Serial.println("");
      command[count] = val;
      count++;
    }
    if (command[0] == 'b')
    {
      Serial.println("EXIT ble test");
      pServer->getAdvertising()->stop();//停止广播
      pService->stop();
      break;
    }

    if (deviceConnected) {//设备连接后，每秒钟发送txValue。
      memset(BLEbuf, 0, 32);
      memcpy(BLEbuf, (char*)"Hello BLE APP!", 32);
      pCharacteristic->setValue(BLEbuf);

      pCharacteristic->notify(); // Send the value to the app!
      Serial.print("*** Sent Value: ");
      Serial.print(BLEbuf);
      Serial.println(" ***");
    }
    delay(1000);
  }
}
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
void loop()
{
  //  Serial.println("******************************  home");
  //测试串口检测
  test_task();
  if (KEY_SCAN() != 0 && test_flag == false)
  {
    sleep_num = 0;
    Serial.print("KEY_NUM CODE: ");
    Serial.println(KEY_NUM);
    switch (KEY_NUM)
    {
      case 1:
        //返回主页
        clear_all();
        show_home_menu();
        Serial.println("return home");
        three_interface_flag = 0;
        scenario_ctl = 0;
        scenario_ctl1 = 0;
        scenario_ctl2 = 0;
        scenario_ctl3 = 0;
        scenario_ctl4 = 0;
        peg_pos = 1; //进入2级界面，功能页选择
        slide_pos = 0;
        prv_menu_pos = 0;
        three_interface_flag = 0;
        Serial.print("peg_pos : ");
        Serial.println(peg_pos);
        break;
      case 2:
        //返回
        if (peg_pos == 1 || peg_pos == 2)
        {
          peg_pos = 1;
          if (prv_menu_pos == 0)
          {
            slide_pos = 0;
            prv_menu_pos = 0;
            three_interface_flag = 0;
            scenario_ctl = 0;
            scenario_ctl1 = 0;
            scenario_ctl2 = 0;
            scenario_ctl3 = 0;
            scenario_ctl4 = 0;
            clear_all();
            show_home_menu();
          }
          else if (prv_menu_pos == 1)
          {
            slide_pos = 1;
            prv_menu_pos = 1;
            three_interface_flag = 0;
            scenario_ctl = 0;
            scenario_ctl1 = 0;
            scenario_ctl2 = 0;
            scenario_ctl3 = 0;
            scenario_ctl4 = 0;
            clear_all();
            show_home_menu1();
          }
          else if (prv_menu_pos == 2)
          {
            slide_pos = 2;
            prv_menu_pos = 2;
            three_interface_flag = 0;
            scenario_ctl = 0;
            scenario_ctl1 = 0;
            scenario_ctl2 = 0;
            scenario_ctl3 = 0;
            scenario_ctl4 = 0;
            clear_all();
            show_home_menu2();
          }
        }
        break;
      case 3:
        //2级界面上滑
        if (peg_pos == 1)
        {
          slide_pos = slide_pos - 1;
          if (slide_pos < 0)
          {
            slide_pos = 0;
          }
          Serial.print("show_home_menu_pos-> slide_pos : ");
          Serial.println(slide_pos);
          Serial.println("");
          show_home_menu_pos(slide_pos);
        }
        //在3级界面上滑
        else if (peg_pos == 2)
        {
          slide_pos = slide_pos - 1;
          if (slide_pos < 0)
          {
            slide_pos = 0;
          }
          if (three_interface_flag == 0)
          {
            Serial.print("show_description-> slide_pos : ");
            Serial.println(slide_pos);
            Serial.println("");
            show_description(slide_pos);
          }
          else if (three_interface_flag == 1)
          {
            Serial.print("show_image_example-> slide_pos : ");
            Serial.println(slide_pos);
            Serial.println("");
            show_image_example(slide_pos);
          }
          else if (three_interface_flag == 2)
          {
            Serial.print("show_scenario_example_pos-> slide_pos : ");
            Serial.println(slide_pos);
            Serial.println("");
            show_scenario_example_pos(slide_pos);
          }
        }
        break;
      case 4:
        //2级界面下滑
        if (peg_pos == 1)
        {
          slide_pos = slide_pos + 1;
          if (slide_pos > 2)
          {
            slide_pos = 2;
          }
          Serial.print("show_home_menu_pos -> slide_pos : ");
          Serial.println(slide_pos);
          Serial.println("");
          show_home_menu_pos(slide_pos);
        }
        //3级界面下滑
        else if (peg_pos == 2)
        {
          if (three_interface_flag == 0)
          {
            slide_pos = slide_pos + 1;
            if (slide_pos > 5)
            {
              slide_pos = 5;
            }
            Serial.print("show_description -> slide_pos : ");
            Serial.println(slide_pos);
            Serial.println("");
            show_description(slide_pos);
          }
          else if (three_interface_flag == 1)
          {
            slide_pos = slide_pos + 1;
            if (slide_pos > 6)
            {
              slide_pos = 6;
            }
            Serial.print("show_image_example -> slide_pos : ");
            Serial.println(slide_pos);
            Serial.println("");
            show_image_example(slide_pos);
          }
          else if (three_interface_flag == 2)
          {
            slide_pos = slide_pos + 1;
            if (slide_pos > 4)
            {
              slide_pos = 4;
            }
            Serial.print("show_scenario_example_pos -> slide_pos : ");
            Serial.println(slide_pos);
            Serial.println("");
            show_scenario_example_pos(slide_pos);
          }
        }
        break;
      case 5:
        //确定
        //2级界面确认
        if (peg_pos == 1)
        {
          Serial.println("ture into 2");
          if (slide_pos == 0)
          {
            Serial.println("into show description");
            Serial.print("show_description -> slide_pos : ");
            Serial.println(slide_pos);
            Serial.println("");
            slide_pos = 0;
            prv_menu_pos = 0;
            peg_pos = 2;
            three_interface_flag = 0;

            clear_all();
            show_description(slide_pos);
          }
          else if (slide_pos == 1)
          {
            Serial.println("into show image example");
            prv_menu_pos = 1;
            slide_pos = 0;
            peg_pos = 2;
            three_interface_flag = 1;

            clear_all();
            show_image_example(0);
          }
          else if (slide_pos == 2)
          {
            Serial.println("into show scenario example");
            //            EPD_HW_RESET();
            slide_pos = 0;
            prv_menu_pos = 2;
            peg_pos = 2;
            three_interface_flag = 2;

            clear_all();
            EPD_ShowPicture(0, 0, EPD_W, EPD_H, gImage_scenario_home, BLACK);
            EPD_DisplayImage(ImageBW);
            EPD_FastUpdate();
            //  EPD_PartUpdate();
            EPD_Sleep();
          }
        }
        //3级界面确认
        else if (peg_pos == 2)
        {
          Serial.println("ture into 3");
          if (three_interface_flag == 2) //在灯光控制界面
          {
            if (slide_pos == 0)
            {
              show_scenario_example_ctl(slide_pos);
            }
            else if (slide_pos == 1)
            {
              show_scenario_example_ctl(slide_pos);
            }
            else if (slide_pos == 2)
            {
              show_scenario_example_ctl(slide_pos);
            }
            else if (slide_pos == 3)
            {
              show_scenario_example_ctl(slide_pos);
            }
            else if (slide_pos == 4)
            {
              show_scenario_example_ctl(slide_pos);
            }
          }
        }
        break;
      default:
        break;
    }
  }
  else if (KEY_SCAN() == 0 && test_flag == false)
  {
    delay(10);
    //    Serial.println("sleep_num +++  ....");
    sleep_num++;
    if (sleep_num == 6000)
    {
      EPD_HW_RESET();
      EPD_Sleep();

      sleep_num = 0;
      //Go to sleep now
      Serial.println("Going to sleep now ....");
      esp_deep_sleep_start();
    }
  }
}

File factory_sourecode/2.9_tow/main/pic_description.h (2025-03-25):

const unsigned char gImage_description[4736] = { /* 0X00,0X01,0X28,0X01,0X80,0X00, */
0XFF,0XFF,0XFF,0XFF,0XFF,0XFF,0XFF,0XFF,0XFF,0XFF,0XFF,0XFF,0XFF,0XFF,0XFF,0XFF,
0XFF,0XFF,0XFF,0XFF,0XFF,0XFF,0XFF,0XFF,0XFF,0XFF,0XFF,0XFF,0XFF,0XFF,0XFF,0XFF,
0XFF,0XFF,0XFF,0XFF,0XFF,0XFF,0XFF,0XFF,0XFF,0XFF,0XFF,0XFF,0XFF,0XFF,0XFF,0XFF,
0XFF,0XFF,0XFF,0XFF,0XFF,0XFF,0XFF,0XFF,0XFF,0XFF,0XFF,0XFF,0XFF,0XFF,0XFF,0XFF,
0XFF,0XFF,0XFF,0XFF,0XFF,0XFF,0XFF,0XFF,0XFF,0XFF,0XFF,0XFF,0XFF,0XFF,0XFF,0XFF,
0XFF,0XFF,0XFF,0XFF,0XFF,0XFF,0XFF,0XFF,0XFF,0XFF,0XFF,0XFF,0XFF,0XFF,0XFF,0XFF,
0XFF,0XFF,0XFF,0XFF,0XFF,0XFF,0XFF,0XFF,0XFF,0XFF,0XFF,0XFF,0XFF,0XFF,0XFF,0XFF,
0XFF,0XFF,0XFF,0XFF,0XFF,0XFF,0XFF,0XFF,0XFF,0XFF,0XFF,0XFF,0XFF,0XFF,0XFF,0XFF,
0XFF,0XFF,0XFF,0XFF,0XFF,0XFF,0XFF,0XFF,0XFF,0XFF,0XFF,0XFF,0XFF,0XFF,0XFF,0XFF,
0XFF,0XFF,0XFF,0XFF,0XFF,0XFF,0XFF,0XFF,0XFF,0XFF,0XFF,0XFF,0XFF,0XFF,0XFF,0XFF,
0XFF,0XFF,0XFF,0XFF,0XFF,0XFF,0XFF,0XFF,0XFF,0XFF,0XFF,0XFF,0XFF,0XFF,0XFF,0XFF,
0XFF,0XFF,0XFF,0XFF,0XFF,0XFF,0XFC,0XFF,0XFF,0XFF,0XFF,0XFF,0XFF,0XFF,0XFF,0XFF,
0XFF,0XFF,0XFF,0XFF,0XFF,0XFF,0XFF,0XFF,0XFF,0XFF,0XFF,0XFF,0XFF,0XFF,0XFF,0XFF,
0XFF,0XFF,0XFF,0XFF,0XFF,0XFF,0XFF,0XFF,0XFF,0XFF,0XFF,0XF8,0X7F,0XFF,0XFF,0XFF,
0XFF,0XFF,0XFF,0XFF,0XFF,0XFF,0XFF,0XFF,0XFF,0XFF,0XFF,0XFF,0XFF,0XFF,0XFF,0XFF,
0XFF,0XFF,0XFF,0XFF,0XFF,0XFF,0XFF,0XFF,0XFF,0XFF,0XFF,0XFF,0XFF,0XFF,0XFF,0XFF,
0XF0,0X3F,0XFF,0XFF,0XFF,0XFF,0XFF,0XFF,0XFF,0XFF,0XFF,0XFF,0XFF,0XFF,0XFF,0XFF,
0XFF,0XFF,0XFF,0XFF,0XFF,0XFF,0XFF,0XFF,0XFF,0XFF,0XFF,0XFF,0XFF,0XFF,0XFF,0XFF,
0XFF,0XFF,0XFF,0XFF,0XFF,0XE0,0X1F,0XFF,0XFF,0XFF,0XFF,0XFF,0XFF,0XFF,0XFF,0XFF,
0XFF,0XFF,0XFF,0XFF,0XFF,0XFF,0XFF,0XFF,0XFF,0XFF,0XFF,0XFF,0XFF,0XFF,0XFF,0XFF,
0XFF,0XFF,0XFF,0XFF,0XFF,0XFF,0XFF,0XFF,0XFF,0XFF,0XC0,0X0F,0XFF,0XFF,0XFF,0XFF,
0XFF,0XFF,0XFF,0XFF,0XFF,0XFF,0XFF,0XFF,0XFF,0XFF,0XFF,0XFF,0XFF,0XFF,0XFF,0XFF,
0XFF,0XFF,0XFF,0XFF,0XFF,0XFF,0XFF,0XFF,0XFF,0XFF,0XFF,0XFF,0XFF,0XFF,0XFF,0X80,
0X07,0XFF,0XFF,0XFF,0XFF,0XFF,0XFF,0XFF,0XFF,0XFF,0XFF,0XFF,0XFF,0XFF,0XFF,0XFF,
0XFF,0XFF,0XFF,0XFF,0XFF,0XFF,0XFF,0XFF,0XFF,0XFF,0XFF,0XFF,0XFF,0XFF,0XFF,0XFF,
0XFF,0XFF,0XFF,0XFF,0X00,0X03,0XFF,0XFF,0XFF,0XFF,0XFF,0XFF,0XFF,0XFF,0XFF,0XFF,
0XFF,0XFF,0XFF,0XFF,0XFF,0XFF,0XFF,0XFF,0XFF,0XFF,0XFF,0XFF,0XFF,0XFF,0XFF,0XFF,
0XFF,0XFF,0XFF,0XFF,0XFF,0XFF,0XFF,0XFF,0XFF,0XE0,0X1F,0XFF,0XFF,0XFF,0XFF,0XFF,
0XFF,0XFF,0XFF,0XFF,0XFF,0XFF,0XFF,0XFF,0XFF,0XFF,0XFF,0XFF,0XFF,0XFF,0XFF,0XFF,
0XFF,0XFF,0XFF,0XFF,0XFF,0XFF,0XFF,0XFF,0XFF,0XFF,0XFF,0XFF,0XFF,0XFF,0XE0,0X1F,
0XFF,0XFF,0XFF,0XFF,0XFF,0XFF,0XFF,0XFF,0XFF,0XFF,0XFF,0XFF,0XFF,0XFF,0XFF,0XFF,
0XFF,0XFF,0XFF,0XFF,0XFF,0XFF,0XFF,0XFF,0XFF,0XFF,0XFF,0XFF,0XFF,0XFF,0XFF,0XFF,
0XFF,0XFF,0XFF,0XE3,0X1F,0XFF,0XFF,0XFF,0XFF,0XFF,0XFF,0XFF,0XFF,0XFF,0XFF,0XFF,
0XFF,0XFF,0XFF,0XFF,0XFF,0XFF,0XFF,0XFF,0XFF,0XFF,0XFF,0XFF,0XFF,0XFF,0XFF,0XFF,
0XFF,0XFF,0XFF,0XFF,0XFF,0XFF,0XFF,0XFF,0XE3,0X1F,0XFF,0XFF,0XFF,0XFF,0XFF,0XFF,
0XFF,0XFF,0XFF,0XFF,0XFF,0XFF,0XFF,0XFF,0XFF,0XFF,0XFF,0XFF,0XFF,0XFF,0XFF,0XFF,
0XFF,0XFF,0XFF,0XFF,0XFF,0XFF,0XFF,0XFF,0XFF,0XFF,0XFF,0XFF,0XFF,0XE3,0X1F,0XFF,
0XFF,0XFF,0XFF,0XFF,0XFF,0XFF,0XFF,0XFF,0XFF,0XFF,0XFF,0XFF,0XFF,0XFF,0XFF,0XFF,
0XFF,0XFF,0XFF,0XFF,0XFF,0XFF,0XFF,0XFF,0XFF,0XFF,0XFF,0XFF,0XFF,0XFF,0XFF,0XFF,
0XFF,0XFF,0XFF,0XFF,0XFF,0XFF,0XFF,0XFF,0XFF,0XFF,0XFF,0XFF,0XFF,0XFF,0XFF,0XFF,
0XFF,0XFF,0XFF,0XFF,0XFF,0XFF,0XFF,0XFF,0XFF,0XFF,0XFF,0XFF,0XFF,0XFF,0XFF,0XFF,
0XFF,0XFF,0XFF,0XFF,0XFF,0XFF,0XFF,0XFF,0XFF,0XFF,0XFF,0XFF,0XFF,0XFF,0XFF,0XFF,
0XFF,0XFF,0XFF,0XFF,0XFF,0XFF,0XFF,0XFF,0XFF,0XFF,0XFF,0XFF,0XFF,0XFF,0XFF,0XFF,
0XFF,0XFF,0XFF,0XFF,0XFF,0XFF,0XFF,0XFF,0XFF,0XFF,0XFF,0XFF,0XFF,0XFF,0XFF,0XFF,
0XFF,0XFF,0XFF,0XFF,0XFF,0XFF,0XFF,0XFF,0XFF,0XFF,0XFF,0XFF,0XFF,0XFF,0XFF,0XFF,
0XFF,0XFF,0XFF,0XFF,0XFF,0XFF,0XFF,0XFF,0XFF,0XFF,0XFF,0XFF,0XFF,0XFF,0XFF,0XFF,
0XFF,0XFF,0XFF,0XFF,0X00,0X00,0X00,0X00,0X00,0X00,0X00,0X00,0X00,0X00,0X00,0X00,
0X00,0X00,0X00,0X00,0X00,0X00,0X00,0X00,0X00,0X00,0X00,0X00,0X00,0X00,0X00,0X00,
0X00,0X00,0X00,0X00,0X00,0X00,0X00,0X00,0X00,0X00,0X00,0X00,0X00,0X00,0X00,0X00,
0X00,0X00,0X00,0X00,0X00,0X00,0X00,0X00,0X00,0X00,0X00,0X00,0X00,0X00,0X00,0X00,
0X00,0X00,0X00,0X00,0X00,0X00,0X00,0X00,0X00,0X00,0X00,0X00,0X00,0X00,0X00,0X00,
0X00,0X00,0X00,0X00,0X00,0X00,0X00,0X00,0X00,0X00,0X00,0X00,0X00,0X00,0X00,0X00,
0X00,0X00,0X00,0X00,0X00,0X00,0X00,0X00,0X00,0X00,0X00,0X00,0X00,0X00,0X00,0X00,
0X00,0X00,0X00,0X00,0X00,0X00,0X00,0X00,0X00,0X00,0X00,0X00,0X00,0X00,0X00,0X00,
0X00,0X00,0X00,0X00,0X00,0X00,0X00,0X00,0X00,0X00,0X00,0X00,0X00,0X00,0X00,0X00,
0X00,0X00,0X00,0X00,0X00,0X00,0X00,0X00,0X00,0X00,0X00,0X00,0X00,0X00,0X00,0X00,
0X00,0X00,0X00,0X00,0X00,0X00,0X00,0X00,0X00,0X00,0X00,0X00,0X00,0X00,0X00,0X00,
0X00,0X00,0X00,0X00,0X00,0X00,0X00,0X00,0X00,0X00,0X00,0X00,0X00,0X00,0X00,0X00,
0X00,0X00,0X00,0X00,0X00,0X00,0X00,0X00,0X00,0X00,0X00,0X00,0X00,0X00,0X00,0X00,
0X00,0X00,0X00,0X00,0X00,0X00,0X00,0X00,0X00,0X00,0X00,0X00,0X00,0X00,0X00,0X00,
0X00,0X00,0X00,0X00,0X00,0X00,0X00,0X00,0X00,0X00,0X00,0X00,0X00,0X00,0X00,0X00,
0X00,0X00,0X00,0X00,0X00,0X00,0X00,0X00,0X00,0X00,0X00,0X00,0X00,0X00,0X00,0X00,
0X00,0X00,0X00,0X00,0X00,0X00,0X00,0X00,0X00,0X00,0X00,0X00,0X00,0X00,0X00,0X00,
0X00,0X00,0X00,0X00,0X00,0X00,0X00,0X00,0X00,0X00,0X00,0X00,0X00,0X00,0X00,0X00,
0X00,0X00,0X00,0X00,0X00,0X00,0X00,0X00,0X00,0X00,0X00,0X00,0X00,0X00,0X00,0X00,
0X00,0X00,0X00,0X00,0X00,0X00,0X00,0X00,0X00,0X00,0X00,0X00,0X00,0X00,0X00,0X00,
0X00,0X00,0X00,0X00,0X00,0X00,0X00,0X00,0X00,0X00,0X00,0X00,0X00,0X00,0X00,0X00,
0X00,0X00,0X00,0X00,0X00,0X00,0X00,0X00,0X00,0X00,0X00,0X00,0X00,0X00,0X00,0X00,
0X00,0X00,0X00,0X00,0X00,0X00,0X00,0X00,0X00,0X00,0X00,0X00,0X00,0X00,0X00,0X00,
0X00,0X00,0X00,0X00,0X00,0X00,0X00,0X00,0X00,0X00,0X00,0X00,0X00,0X00,0X00,0X00,
0X00,0X00,0X00,0X00,0X00,0X00,0X00,0X00,0X00,0X00,0X00,0X00,0X00,0X00,0X00,0X00,
0X00,0X00,0X00,0X00,0X00,0X00,0X00,0X00,0X00,0X00,0X00,0X00,0X00,0X00,0X00,0X00,
0X00,0X00,0X00,0X00,0X00,0X00,0X00,0X00,0X00,0X00,0X00,0X00,0X00,0X00,0X00,0X00,
0X00,0X00,0X00,0X00,0X00,0X00,0X00,0X00,0X00,0X00,0X00,0X00,0X00,0X00,0X00,0X00,
0X00,0X00,0X00,0X00,0X00,0X01,0XC0,0X00,0X00,0X00,0X00,0X00,0X00,0X00,0X00,0X00,
0X00,0XC0,0X00,0X01,0XC0,0X00,0X00,0X00,0X00,0X00,0X00,0X00,0X00,0X00,0X00,0X00,
0X00,0X00,0X00,0X00,0X00,0X00,0X1F,0XC0,0X00,0X00,0X01,0XC0,0X00,0X00,0X00,0X03,
0XF8,0X00,0X00,0X00,0X00,0X00,0XC0,0X00,0X01,0XC0,0X00,0X00,0X00,0X00,0X00,0X00,
0X00,0X00,0X00,0X00,0X00,0X00,0X00,0X00,0X00,0X00,0X00,0X1F,0XF0,0X00,0X00,0X01,
0XC0,0X00,0X00,0X38,0X03,0XFC,0X00,0X00,0X00,0X00,0X00,0X00,0X00,0X60,0X00,0X00,
0X00,0X00,0X00,0X00,0X00,0X00,0X00,0X00,0X00,0X00,0X00,0X00,0X00,0X00,0X00,0X00,
0X1C,0X78,0X00,0X00,0X01,0XC0,0X00,0X00,0X38,0X03,0X8E,0X00,0X00,0X00,0X00,0X00,
0X00,0X00,0X60,0X00,0X00,0X00,0X00,0X00,0X00,0X00,0X00,0X00,0X00,0X00,0X00,0X00,
0X00,0X00,0X00,0X00,0X00,0X1C,0X39,0XD8,0X78,0X1D,0XCE,0X38,0X78,0XFC,0X03,0X87,
0X07,0X03,0XC0,0X78,0X6C,0XC7,0X71,0XF9,0XC1,0XE0,0XCE,0X00,0X00,0X00,0X00,0X00,
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
